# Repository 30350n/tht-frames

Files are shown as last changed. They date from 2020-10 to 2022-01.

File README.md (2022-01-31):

  

# THT-Frames

THT-Frames is a through hole version of [Mutable Instruments Frames](https://mutable-instruments.net/modules/frames/).
For the MCU a **128KB** STM32F103C8T6/STM32F103CBT6 "bluepill type" module is used.
**Warning! Most of the conventional boards floating around on ebay, aliexpress, etc. are 64KB. Those won't work with the provided firmware.**
I'd recommend picking one up from robotdyn ([website](https://robotdyn.com/)/[aliexpress](https://robotdyn.aliexpress.com/store/1950989)), these are the ones I use and they work without any problems.
You can also pickup a matching APM32 board if you want for a little cheaper. I've tested them and they also seem to work fine.

It also uses a different dac than the original, because it isn't available as a DIP package.

## Panels

Be sure to check out my [printable-instruments](https://github.com/30350n/printable-instruments) repository, which contains pcb panels for several Mutable Instuments modules including Frames.
That being said, any third-party panels should also fit with these boards.

## How to use

### Quickstart

To get started quickly, you can just download the gerbers for both pcbs and the compiled software `.hex` file from the [Releases](https://github.com/30350n/tht-frames/releases) section.

### Hardware

If you want to export the gerbers yourself or modify them, just clone the repository and open the hardware files with KiCad.

### Software

This project requires slightly modified software, because it uses two 2-channel DACs instead of the single 4-channel DAC the original uses.

If you want to build the software yourself, clone the [mutable-dev-environment](https://github.com/pichenettes/mutable-dev-environment) repository and follow the provided instructions to set it up.
After that, copy the patch from this repository (`software/tht-frames.patch`) to `mutable-dev-environment/eurorack-modules` and also `cd` to that directory.
Finally apply the patch via `git apply tht-frames.patch` and build the firmware as usual.

## Credits
- **[Mutable Instruments](https://github.com/pichenettes/eurorack)** provided the original hardware design files and software which this projects builds upon.
- **[SoundForce - Braids Through-hole](http://sound-force.nl/?page_id=3179)** gave me the idea for this project.

## License
- Hardware: cc-by-sa-3.0
- Software: MIT

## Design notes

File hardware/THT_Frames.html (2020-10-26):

# E:\projects\modular\modules\prototypes\THT_Frames\THT_Frames.sch

09/26/20 14:19:38

Eeschema (5.1.6)-1

Component Count:144

Ref | Qnty | Value | Part | Datasheet | Description | Vendor
C1, C2, C3, C4, C5 | 5 | 560pF | Device:C | ~ | Unpolarized capacitor
C6, C7, C8, C9, C16, C17 | 6 | 18pF | Device:C | ~ | Unpolarized capacitor
C10, C11, C12 | 3 | 10uF | Device:CP_Small | ~ | Polarized capacitor, small symbol
C13, C14 | 2 | 22uF | Device:CP | ~ | Polarized capacitor
C15, C18, C19, C20, C21, C22, C23, C26, C27, C34, C35, C36, C37, C38, C39 | 15 | 100nF | Device:C | ~ | Unpolarized capacitor
C24, C25, C28, C29 | 4 | 1uF | Device:CP | ~ | Polarized capacitor
D1, D2 | 2 | BAT85 | Diode:BAT85 | https://assets.nexperia.com/documents/data-sheet/BAT85.pdf | 30V 0.2A Schottky barrier single diode, DO-35
D3 | 1 | LED_CRGB | Device:LED_CRGB | ~ | RGB LED, cathode/red/green/blue
D4 | 1 | LED_FRAME | Device:LED | ~ | Light emitting diode
D5 | 1 | LED_CH4 | Device:LED | ~ | Light emitting diode
D6 | 1 | LED_CH3 | Device:LED | ~ | Light emitting diode
D7 | 1 | LED_CH2 | Device:LED | ~ | Light emitting diode
D8 | 1 | LED_CH1 | Device:LED | ~ | Light emitting diode
D9, D10, D11 | 3 | 1N5819 | Diode:1N5819 | http://www.vishay.com/docs/88525/1n5817.pdf | 40V 1A Schottky Barrier Rectifier Diode, DO-41
J1 | 1 | FRAME_IN | Connector:AudioJack2_SwitchT | ~ | Audio Jack, 2 Poles (Mono / TS), Switched T Pole (Normalling)
J2 | 1 | Serial | Connector_Generic:Conn_01x06 | ~ | Generic connector, single row, 01x06, script generated (kicad-library-utils/schlib/autogen/connector/)
J3, J18, J21 | 3 | Conn_01x12_Male | Connector:Conn_01x12_Male | ~ | Generic connector, single row, 01x12, script generated (kicad-library-utils/schlib/autogen/connector/)
J5 | 1 | STEP_OUT | Connector:AudioJack2_SwitchT | ~ | Audio Jack, 2 Poles (Mono / TS), Switched T Pole (Normalling)
J6 | 1 | 1_IN | Connector:AudioJack2_SwitchT | ~ | Audio Jack, 2 Poles (Mono / TS), Switched T Pole (Normalling)
J7 | 1 | 2_IN | Connector:AudioJack2_SwitchT | ~ | Audio Jack, 2 Poles (Mono / TS), Switched T Pole (Normalling)
J8 | 1 | 3_IN | Connector:AudioJack2_SwitchT | ~ | Audio Jack, 2 Poles (Mono / TS), Switched T Pole (Normalling)
J9 | 1 | 4_IN | Connector:AudioJack2_SwitchT | ~ | Audio Jack, 2 Poles (Mono / TS), Switched T Pole (Normalling)
J10 | 1 | 1_OUT | Connector:AudioJack2_SwitchT | ~ | Audio Jack, 2 Poles (Mono / TS), Switched T Pole (Normalling)
J11 | 1 | 2_OUT | Connector:AudioJack2_SwitchT | ~ | Audio Jack, 2 Poles (Mono / TS), Switched T Pole (Normalling)
J12 | 1 | 3_OUT | Connector:AudioJack2_SwitchT | ~ | Audio Jack, 2 Poles (Mono / TS), Switched T Pole (Normalling)
J13 | 1 | 4_OUT | Connector:AudioJack2_SwitchT | ~ | Audio Jack, 2 Poles (Mono / TS), Switched T Pole (Normalling)
J14 | 1 | POWER | Connector_Generic:Conn_02x08_Odd_Even | ~ | Generic connector, double row, 02x08, odd/even pin numbering scheme (row 1 odd numbers, row 2 even numbers), script generated (kicad-library-utils/schlib/autogen/connector/)
J15 | 1 | OFFSET_JUMPER | Connector_Generic:Conn_01x03 | ~ | Generic connector, single row, 01x03, script generated (kicad-library-utils/schlib/autogen/connector/)
J16 | 1 | ALL_IN | Connector:AudioJack2_SwitchT | ~ | Audio Jack, 2 Poles (Mono / TS), Switched T Pole (Normalling)
J17 | 1 | MIX_OUT | Connector:AudioJack2_SwitchT | ~ | Audio Jack, 2 Poles (Mono / TS), Switched T Pole (Normalling)
J19, J20, J22 | 3 | Conn_01x12_Female | Connector:Conn_01x12_Female | ~ | Generic connector, single row, 01x12, script generated (kicad-library-utils/schlib/autogen/connector/)
Q1 | 1 | 2N3904 | Transistor_BJT:2N3904 | https://www.fairchildsemi.com/datasheets/2N/2N3904.pdf | 0.2A Ic, 40V Vce, Small Signal NPN Transistor, TO-92
R1, R2, R3, R19, R20, R21, R22, R23, R24, R29, R30, R31, R32, R33, R34, R35, R36, R37, R38, R39, R40, R41, R42, R43, R44, R46, R47 | 27 | 100k | Device:R | ~ | Resistor
R4 | 1 | 240k | Device:R | ~ | Resistor
R5 | 1 | 33k | Device:R | ~ | Resistor
R6, R48, R49, R50, R51, R52 | 6 | 1k | Device:R | ~ | Resistor
R7 | 1 | 10k | Device:R | ~ | Resistor
R8, R9, R10, R11, R12, R13, R14, R15, R53, R54, R55, R56 | 12 | 100 | Device:R | ~ | Resistor
R16, R18 | 2 | 4.7k | Device:R | ~ | Resistor
R17 | 1 | 3.3k | Device:R | ~ | Resistor
R25, R26, R27, R28 | 4 | 510 | Device:R | ~ | Resistor
R45 | 1 | 49.9k | Device:R | ~ | Resistor
RV1, RV2, RV3, RV4, RV5, RV6 | 6 | 10k | Device:R_POT_MountingPin | ~ | Potentiometer with a mounting pin
SW1 | 1 | ADD | Switch:SW_SPST | ~ | Single Pole Single Throw (SPST) switch
SW2 | 1 | DEL | Switch:SW_SPST | ~ | Single Pole Single Throw (SPST) switch
SW3 | 1 | OFFSET | Switch:SW_SPDT | ~ | Switch, single pole double throw
U1, U5, U13 | 3 | TL072 | Amplifier_Operational:TL072 | http://www.ti.com/lit/ds/symlink/tl071.pdf | Dual Low-Noise JFET-Input Operational Amplifiers, DIP-8/SOIC-8
U2 | 1 | bluepill | custom:bluepill
U3 | 1 | LM1117-3.3 | Regulator_Linear:LM1117-3.3 | http://www.ti.com/lit/ds/symlink/lm1117.pdf | 800mA Low-Dropout Linear Regulator, 3.3V fixed output, TO-220/TO-252/TO-263/SOT-223
U4 | 1 | LM4040AIZ-10 | Reference_Voltage:LM4040DBZ-10 | http://www.ti.com/lit/ds/symlink/lm4040-n.pdf | 10.00V Precision Micropower Shunt Voltage Reference, SOT-23
U6, U7 | 2 | MCP4822 | Analog_DAC:MCP4822 | http://ww1.microchip.com/downloads/en/DeviceDoc/20002249B.pdf | 2-Channel 12-Bit D/A Converters with SPI Interface and Internal Reference (2.048V)
U8, U9 | 2 | TL074 | Amplifier_Operational:TL074 | http://www.ti.com/lit/ds/symlink/tl071.pdf | Quad Low-Noise JFET-Input Operational Amplifiers, DIP-14/SOIC-14
U12 | 1 | V2164 | custom:V2164

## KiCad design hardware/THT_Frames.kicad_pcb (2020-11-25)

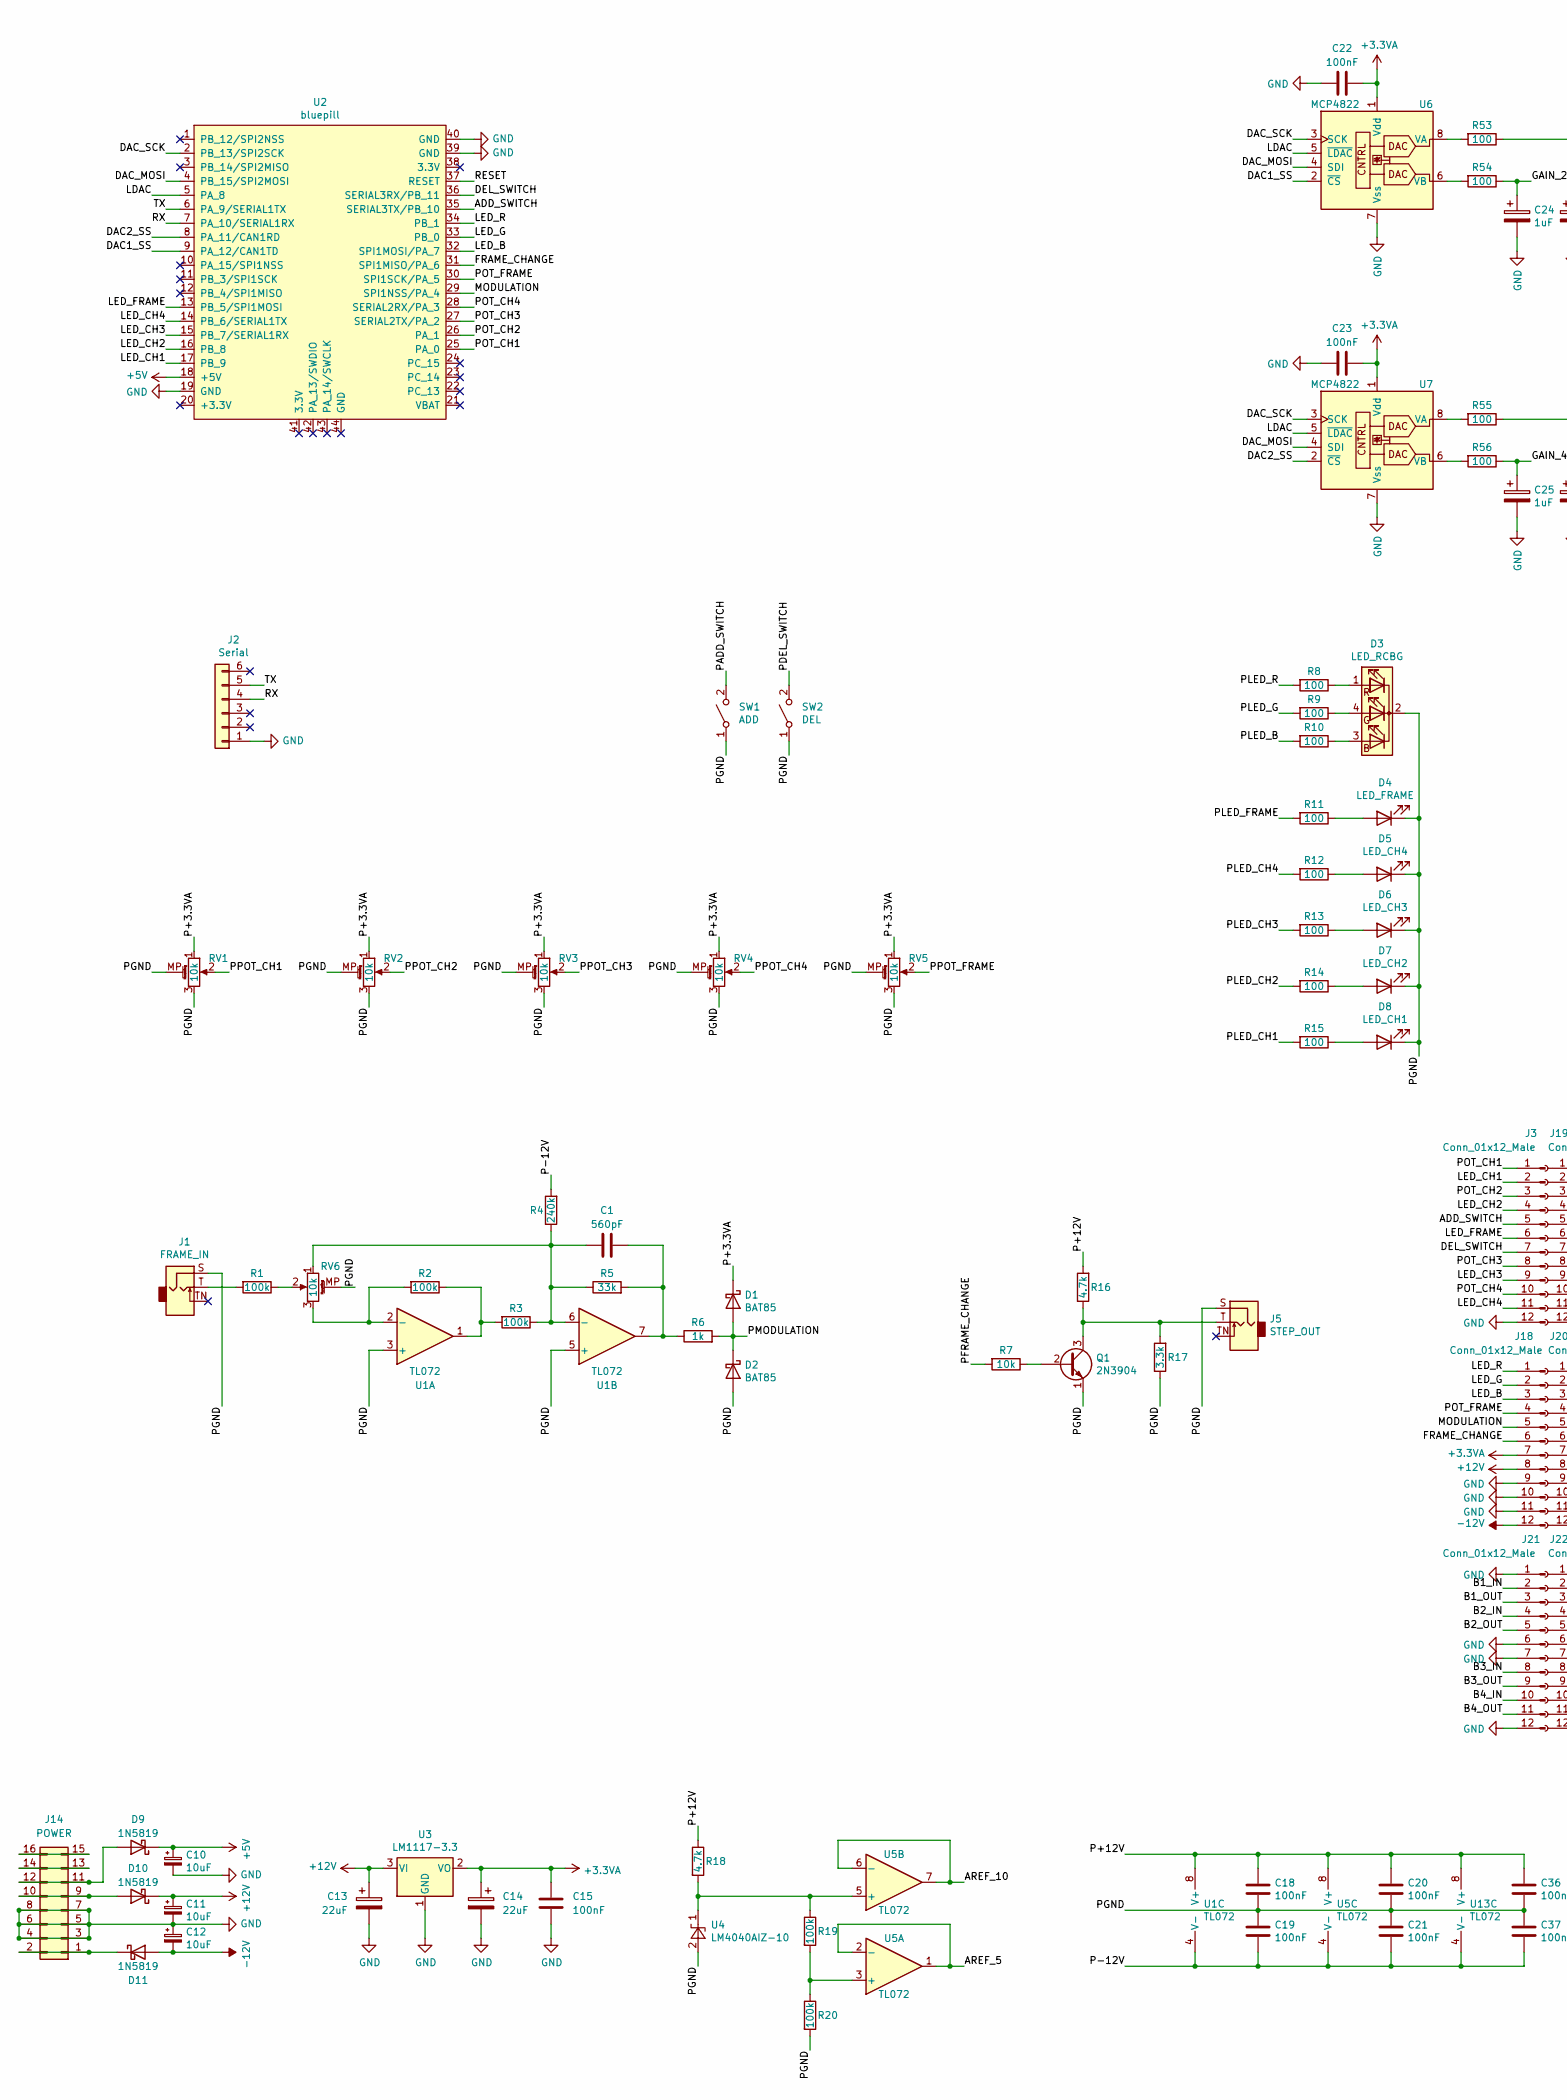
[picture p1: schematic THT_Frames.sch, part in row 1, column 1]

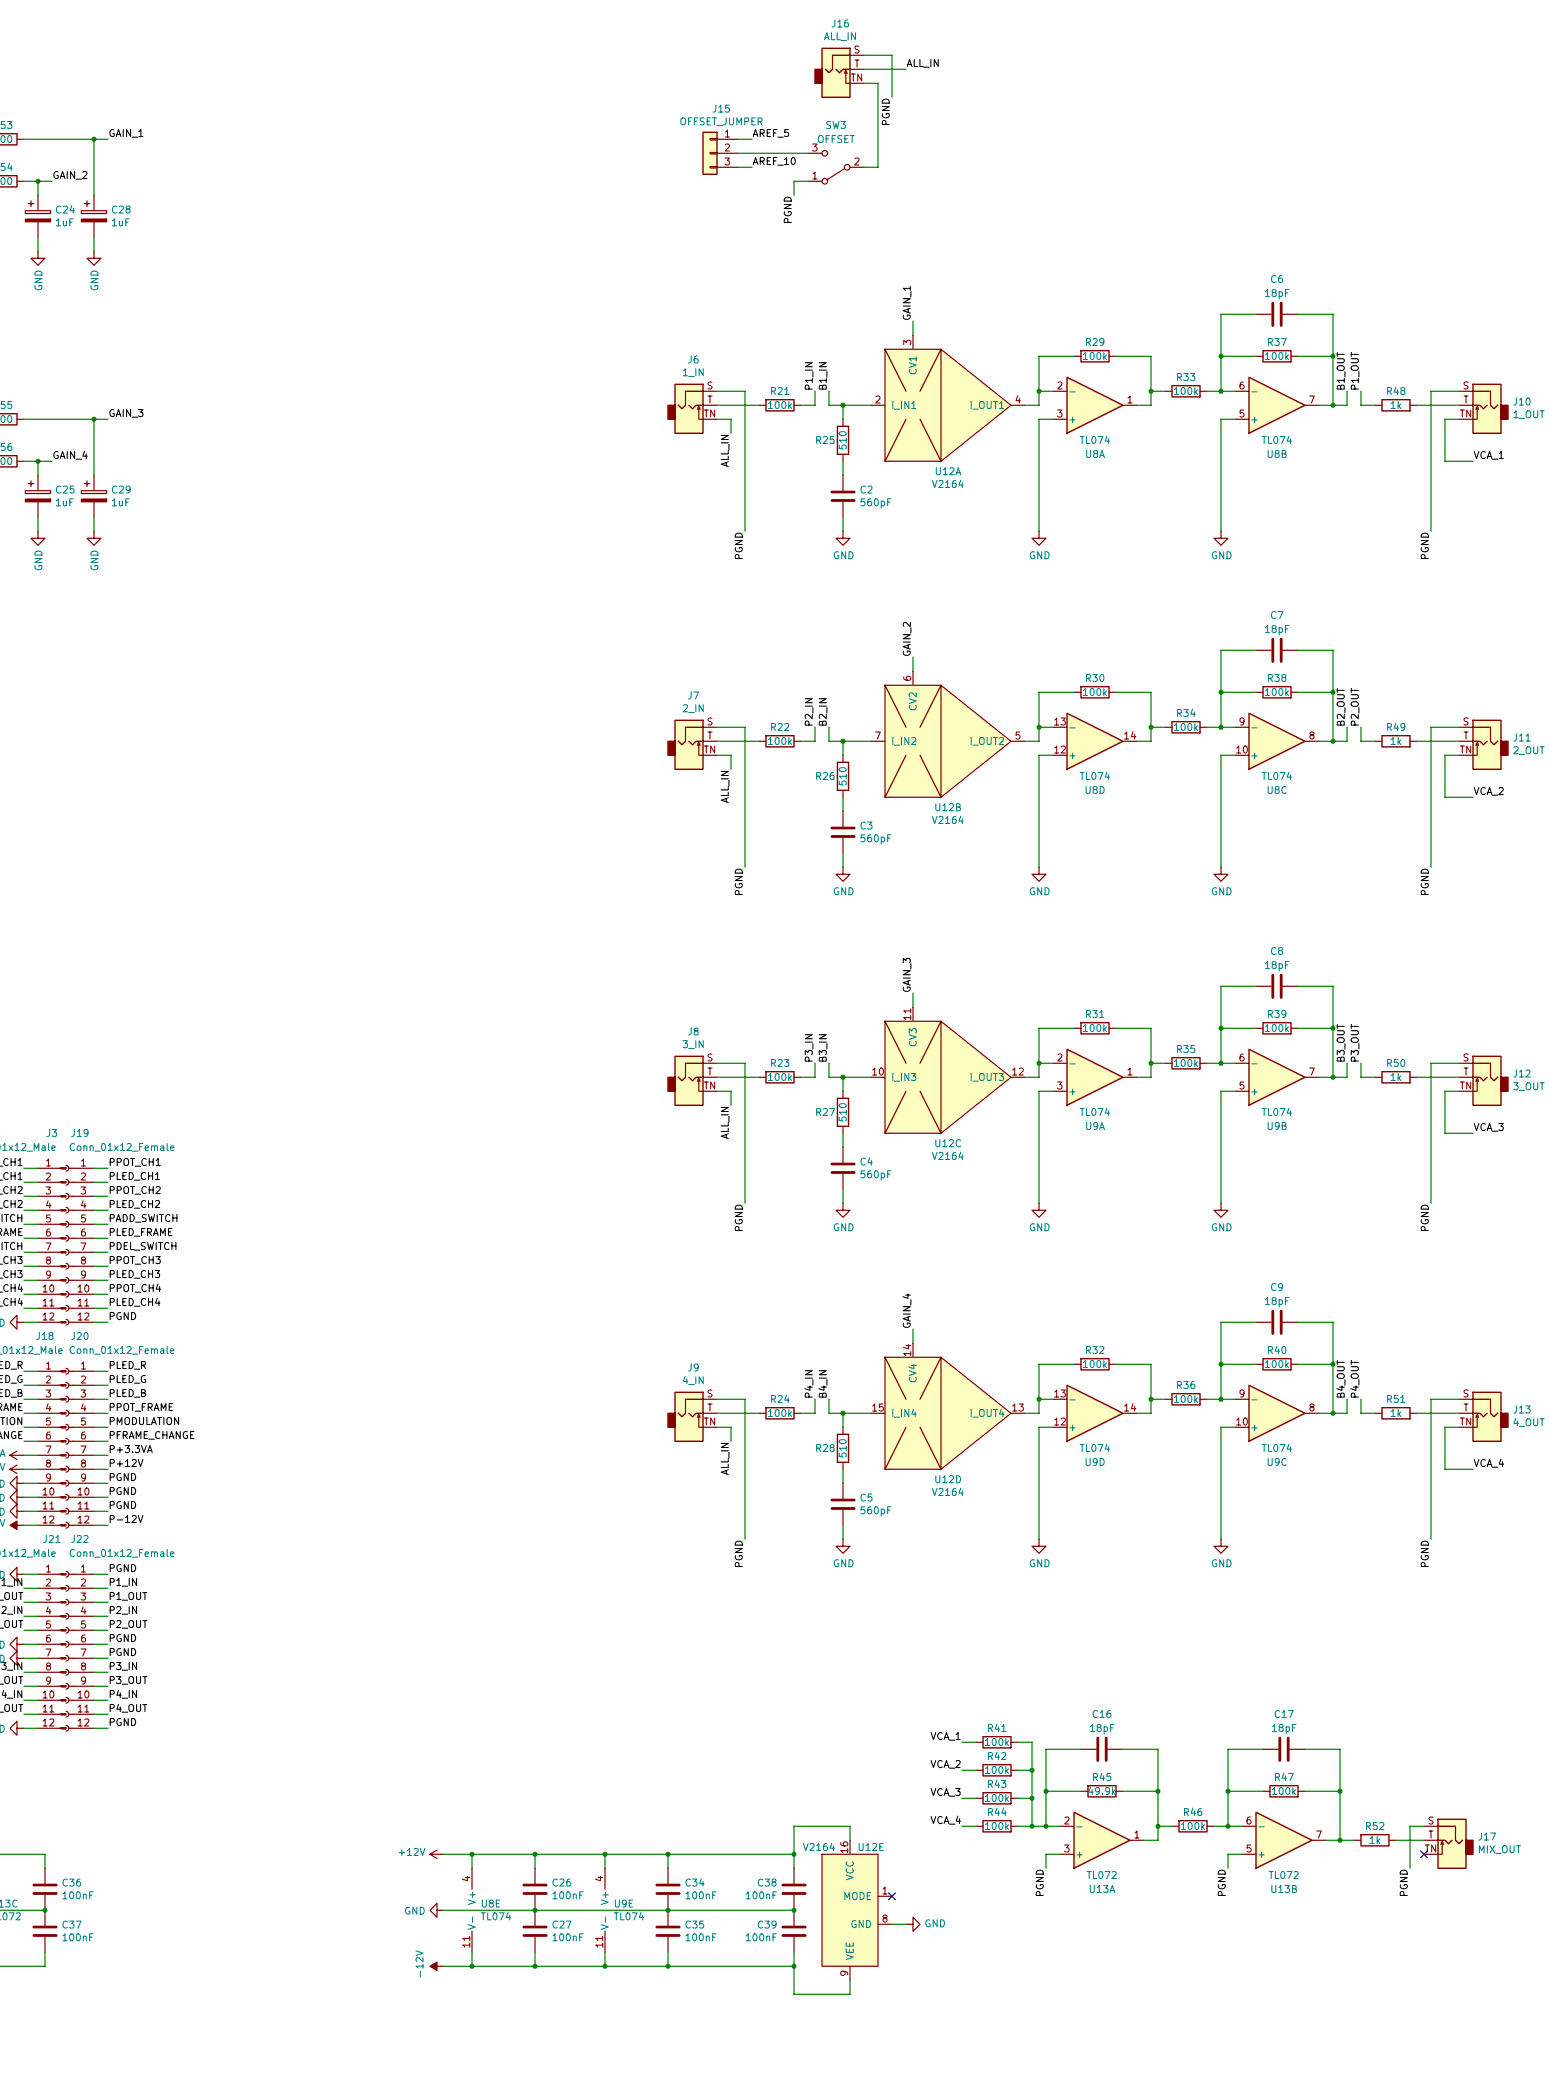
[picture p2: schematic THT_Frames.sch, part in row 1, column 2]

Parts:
C1, C2, C3, C4, C5: 560pF; C_Disc_D5.0mm_W2.5mm_P5.00mm_silk
C6, C7, C8, C9, C16, C17: 18pF; C_Disc_D5.0mm_W2.5mm_P5.00mm_silk
C10, C11, C12: 10uF; CP_Radial_D5.0mm_P2.00mm_silk
C13, C14: 22uF; CP_Radial_D5.0mm_P2.00mm_silk
C15, C18, C19, C20, C21, C22, C23, C26, C27, C34, C35, C36, C37, C38, C39: 100nF; C_Disc_D5.0mm_W2.5mm_P5.00mm_silk
C24, C25, C28, C29: 1uF; C_Disc_D7.5mm_W5.0mm_P5.00mm_silk
D1, D2: BAT85; D_DO-41_SOD81_P7.62mm_Horizontal_silk
D3: LED_RCBG; LED_D5.0mm-4_RGB
D4: LED_FRAME; LED_D5.0mm
D5: LED_CH4; LED_D3.0mm
D6: LED_CH3; LED_D3.0mm
D7: LED_CH2; LED_D3.0mm
D8: LED_CH1; LED_D3.0mm
D9, D10, D11: 1N5819; D_DO-41_SOD81_P10.16mm_Horizontal_silk
J1: FRAME_IN; Jack_3.5mm_QingPu_WQP-PJ398SM_Vertical_CircularHoles_better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
J2: Serial; PinHeader_1x06_P2.54mm_Vertical
J3, J18, J21: Conn_01x12_Male; PinHeader_1x12_P2.54mm_Vertical
J5: STEP_OUT; Jack_3.5mm_QingPu_WQP-PJ398SM_Vertical_CircularHoles_better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
J6: 1_IN; Jack_3.5mm_QingPu_WQP-PJ398SM_Vertical_CircularHoles_better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
J7: 2_IN; Jack_3.5mm_QingPu_WQP-PJ398SM_Vertical_CircularHoles_better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
J8: 3_IN; Jack_3.5mm_QingPu_WQP-PJ398SM_Vertical_CircularHoles_better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
J9: 4_IN; Jack_3.5mm_QingPu_WQP-PJ398SM_Vertical_CircularHoles_better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
J10: 1_OUT; Jack_3.5mm_QingPu_WQP-PJ398SM_Vertical_CircularHoles_better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
J11: 2_OUT; Jack_3.5mm_QingPu_WQP-PJ398SM_Vertical_CircularHoles_better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
J12: 3_OUT; Jack_3.5mm_QingPu_WQP-PJ398SM_Vertical_CircularHoles_better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
J13: 4_OUT; Jack_3.5mm_QingPu_WQP-PJ398SM_Vertical_CircularHoles_better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
J14: POWER; IDC-Header_2x08_P2.54mm_Vertical_eurorack
J15: OFFSET_JUMPER; PinHeader_1x03_P2.54mm_Vertical
J16: ALL_IN; Jack_3.5mm_QingPu_WQP-PJ398SM_Vertical_CircularHoles_better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
J17: MIX_OUT; Jack_3.5mm_QingPu_WQP-PJ398SM_Vertical_CircularHoles_better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
J19, J20, J22: Conn_01x12_Female; PinSocket_1x12_P2.54mm_Vertical
Q1: 2N3904; TO-92_Inline_Wide_silk
R1, R2, R3, R19, R20, R21, R22, R23, R24, R29, R30, R31, R32, R33, R34, R35, R36, R37, R38, R39, R40, R41, R42, R43, R44, R46, R47: 100k; R_Axial_DIN0207_L6.3mm_D2.5mm_P7.62mm_Horizontal_silk
R4: 240k; R_Axial_DIN0207_L6.3mm_D2.5mm_P7.62mm_Horizontal_silk
R5: 33k; R_Axial_DIN0207_L6.3mm_D2.5mm_P7.62mm_Horizontal_silk
R6, R48, R49, R50, R51, R52: 1k; R_Axial_DIN0207_L6.3mm_D2.5mm_P7.62mm_Horizontal_silk
R7: 10k; R_Axial_DIN0207_L6.3mm_D2.5mm_P7.62mm_Horizontal_silk
R8, R9, R10, R11, R12, R13, R14, R15, R53, R54, R55, R56: 100; R_Axial_DIN0207_L6.3mm_D2.5mm_P7.62mm_Horizontal_silk
R16, R18: 4.7k; R_Axial_DIN0207_L6.3mm_D2.5mm_P7.62mm_Horizontal_silk
R17: 3.3k; R_Axial_DIN0207_L6.3mm_D2.5mm_P7.62mm_Horizontal_silk
R25, R26, R27, R28: 510; R_Axial_DIN0207_L6.3mm_D2.5mm_P7.62mm_Horizontal_silk
R45: 49.9k; R_Axial_DIN0207_L6.3mm_D2.5mm_P7.62mm_Horizontal_silk
RV1, RV2, RV3, RV4, RV5, RV6: 10k; Potentiometer_Alps_RK09K_Single_Vertical_better_origin
SW1: ADD; Push_E-Switch_KS01Q01_silk_better_origin
SW2: DEL; Push_E-Switch_KS01Q01_silk_better_origin
SW3: OFFSET; sw_spdt_slide_CS12ANW03
U1, U5, U13: TL072; DIP-8_W7.62mm_Socket_LongPads_silk
U2: bluepill
U3: LM1117-3.3; TO-220-3_Horizontal_TabDown_silk
U4: LM4040AIZ-10; TO-92_Inline_Wide_silk
U6, U7: MCP4822; DIP-8_W7.62mm_Socket_LongPads_silk
U8, U9: TL074; DIP-14_W7.62mm_Socket_LongPads_silk
U12: V2164; DIP-16_W7.62mm_Socket_LongPads_silk

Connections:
+3.3VA: C14.1, C15.1, C22.1, C23.1, J18.7, U3.2 (VO), U6.1 (Vdd), U7.1 (Vdd)
+5V: C10.1, D9.1 (K), U2.18 (+5V)
+12V: C11.1, C13.1, C26.1, C34.1, C38.1, D10.1 (K), J18.8, U3.3 (VI), U8.4 (V+), U9.4 (V+), U12.16 (VCC)
-12V: C12.2, C27.2, C35.2, C39.2, D11.2 (A), J18.12, U8.11 (V-), U9.11 (V-), U12.9 (VEE)
/ADD_SWITCH: J3.5, U2.35 (SERIAL3TX/PB_10)
/ALL_IN: J6.TN, J7.TN, J8.TN, J9.TN, J16.T
/AREF_5: J15.1, U5.1, U5.2 (-)
/AREF_10: J15.3, U5.6 (-), U5.7
/B1_IN: J21.2, R25.1, U12.2 (I_IN1)
/B1_OUT: C6.1, J21.3, R37.2, U8.7
/B2_IN: J21.4, R26.1, U12.7 (I_IN2)
/B2_OUT: C7.1, J21.5, R38.2, U8.8
/B3_IN: J21.8, R27.1, U12.10 (I_IN3)
/B3_OUT: C8.1, J21.9, R39.2, U9.7
/B4_IN: J21.10, R28.1, U12.15 (I_IN4)
/B4_OUT: C9.1, J21.11, R40.2, U9.8
/DAC1_SS: U2.9 (PA_12/CAN1TD), U6.2 (~CS)
/DAC2_SS: U2.8 (PA_11/CAN1RD), U7.2 (~CS)
/DAC_MOSI: U2.4 (PB_15/SPI2MOSI), U6.4 (SDI), U7.4 (SDI)
/DAC_SCK: U2.2 (PB_13/SPI2SCK), U6.3 (SCK), U7.3 (SCK)
/DEL_SWITCH: J3.7, U2.36 (SERIAL3RX/PB_11)
/FRAME_CHANGE: J18.6, U2.31 (SPI1MISO/PA_6)
/GAIN_1: C28.1, R53.1, U12.3 (CV1)
/GAIN_2: C24.1, R54.1, U12.6 (CV2)
/GAIN_3: C29.1, R55.1, U12.11 (CV3)
/GAIN_4: C25.1, R56.1, U12.14 (CV4)
/LDAC: U2.5 (PA_8), U6.5 (~LDAC), U7.5 (~LDAC)
/LED_B: J18.3, U2.32 (SPI1MOSI/PA_7)
/LED_CH1: J3.2, U2.17 (PB_9)
/LED_CH2: J3.4, U2.16 (PB_8)
/LED_CH3: J3.9, U2.15 (PB_7/SERIAL1RX)
/LED_CH4: J3.11, U2.14 (PB_6/SERIAL1TX)
/LED_FRAME: J3.6, U2.13 (PB_5/SPI1MOSI)
/LED_G: J18.2, U2.33 (PB_0)
/LED_R: J18.1, U2.34 (PB_1)
/MODULATION: J18.5, U2.29 (SPI1NSS/PA_4)
/P1_IN: J22.2, R21.1
/P1_OUT: J22.3, R48.1
/P2_IN: J22.4, R22.1
/P2_OUT: J22.5, R49.1
/P3_IN: J22.8, R23.1
/P3_OUT: J22.9, R50.1
/P4_IN: J22.10, R24.1
/P4_OUT: J22.11, R51.1
/P+3.3VA: D1.1 (K), J20.7, RV1.1, RV2.1, RV3.1, RV4.1, RV5.1
/P+12V: C18.1, C20.1, C36.1, J20.8, R16.2, R18.1, U1.8 (V+), U5.8 (V+), U13.8 (V+)
/P-12V: C19.2, C21.2, C37.2, J20.12, R4.2, U1.4 (V-), U5.4 (V-), U13.4 (V-)
/PADD_SWITCH: J19.5, SW1.2 (B)
/PDEL_SWITCH: J19.7, SW2.2 (B)
/PFRAME_CHANGE: J20.6, R7.2
/PGND: C18.2, C19.1, C20.2, C21.1, C36.2, C37.1, D2.2 (A), D3.2 (K), D4.1 (K), D5.1 (K), D6.1 (K), D7.1 (K), D8.1 (K), J1.S, J5.S, J6.S, J7.S, J8.S, J9.S, J10.S, J11.S, J12.S, J13.S, J16.S, J17.S, J19.12, J20.9, J20.10, J20.11, J22.1, J22.6, J22.7, J22.12, Q1.1 (E), R17.1, R20.2, RV1.3, RV1.MP (MountPin), RV2.3, RV2.MP (MountPin), RV3.3, RV3.MP (MountPin), RV4.3, RV4.MP (MountPin), RV5.3, RV5.MP (MountPin), RV6.MP (MountPin), SW1.1 (A), SW2.1 (A), SW3.1 (A), U1.3 (+), U1.5 (+), U4.2 (A), U13.3 (+), U13.5 (+)
/PLED_B: J20.3, R10.2
/PLED_CH1: J19.2, R15.2
/PLED_CH2: J19.4, R14.2
/PLED_CH3: J19.9, R13.2
/PLED_CH4: J19.11, R12.2
/PLED_FRAME: J19.6, R11.2
/PLED_G: J20.2, R9.2
/PLED_R: J20.1, R8.2
/PMODULATION: D1.2 (A), D2.1 (K), J20.5, R6.2
/POT_CH1: J3.1, U2.25 (PA_0)
/POT_CH2: J3.3, U2.26 (PA_1)
/POT_CH3: J3.8, U2.27 (SERIAL2TX/PA_2)
/POT_CH4: J3.10, U2.28 (SERIAL2RX/PA_3)
/POT_FRAME: J18.4, U2.30 (SPI1SCK/PA_5)
/PPOT_CH1: J19.1, RV1.2
/PPOT_CH2: J19.3, RV2.2
/PPOT_CH3: J19.8, RV3.2
/PPOT_CH4: J19.10, RV4.2
/PPOT_FRAME: J20.4, RV5.2
/RESET: U2.37 (RESET)
/RX: J2.4, U2.7 (PA_10/SERIAL1RX)
/TX: J2.5, U2.6 (PA_9/SERIAL1TX)
/VCA_1: J10.TN, R41.1
/VCA_2: J11.TN, R42.1
/VCA_3: J12.TN, R43.1
/VCA_4: J13.TN, R44.1
GND: C2.2, C3.2, C4.2, C5.2, C10.2, C11.2, C12.1, C13.2, C14.2, C15.2, C22.2, C23.2, C24.2, C25.2, C26.2, C27.1, C28.2, C29.2, C34.2, C35.1, C38.2, C39.1, J2.1, J3.12, J14.3, J14.4, J14.5, J14.6, J14.7, J14.8, J18.9, J18.10, J18.11, J21.1, J21.6, J21.7, J21.12, U2.19 (GND), U2.39 (GND), U2.40 (GND), U3.1 (GND), U6.7 (Vss), U7.7 (Vss), U8.3 (+), U8.5 (+), U8.10 (+), U8.12 (+), U9.3 (+), U9.5 (+), U9.10 (+), U9.12 (+), U12.8 (GND)
unnamed: C1.1, R5.2, R6.1, U1.7
unnamed: C1.2, R3.1, R4.1, R5.1, RV6.1, U1.6 (-)
unnamed: C2.1, R25.2
unnamed: C3.1, R26.2
unnamed: C4.1, R27.2
unnamed: C5.1, R28.2
unnamed: C6.2, R33.2, R37.1, U8.6 (-)
unnamed: C7.2, R34.2, R38.1, U8.9 (-)
unnamed: C8.2, R35.2, R39.1, U9.6 (-)
unnamed: C9.2, R36.2, R40.1, U9.9 (-)
unnamed: C16.1, R45.1, R46.2, U13.1
unnamed: C16.2, R41.2, R42.2, R43.2, R44.2, R45.2, U13.2 (-)
unnamed: C17.1, R47.2, R52.2, U13.7
unnamed: C17.2, R46.1, R47.1, U13.6 (-)
unnamed: D3.1 (RA), R8.1
unnamed: D3.3 (BA), R10.1
unnamed: D3.4 (GA), R9.1
unnamed: D4.2 (A), R11.1
unnamed: D5.2 (A), R12.1
unnamed: D6.2 (A), R13.1
unnamed: D7.2 (A), R14.1
unnamed: D8.2 (A), R15.1
unnamed: D9.2 (A), J14.11, J14.12
unnamed: D10.2 (A), J14.9, J14.10
unnamed: D11.1 (K), J14.1, J14.2
unnamed: J1.T, R1.2
unnamed: J5.T, Q1.3 (C), R16.1, R17.2
unnamed: J6.T, R21.2
unnamed: J7.T, R22.2
unnamed: J8.T, R23.2
unnamed: J9.T, R24.2
unnamed: J10.T, R48.2
unnamed: J11.T, R49.2
unnamed: J12.T, R50.2
unnamed: J13.T, R51.2
unnamed: J14.13, J14.14
unnamed: J14.15, J14.16
unnamed: J15.2, SW3.3 (C)
unnamed: J16.TN, SW3.2 (B)
unnamed: J17.T, R52.1
unnamed: Q1.2 (B), R7.1
unnamed: R1.1, RV6.2
unnamed: R2.1, R3.2, U1.1
unnamed: R2.2, RV6.3, U1.2 (-)
unnamed: R18.2, R19.1, U4.1 (K), U5.5 (+)
unnamed: R19.2, R20.1, U5.3 (+)
unnamed: R29.1, R33.1, U8.1
unnamed: R29.2, U8.2 (-), U12.4 (I_OUT1)
unnamed: R30.1, R34.1, U8.14
unnamed: R30.2, U8.13 (-), U12.5 (I_OUT2)
unnamed: R31.1, R35.1, U9.1
unnamed: R31.2, U9.2 (-), U12.12 (I_OUT3)
unnamed: R32.1, R36.1, U9.14
unnamed: R32.2, U9.13 (-), U12.13 (I_OUT4)
unnamed: R53.2, U6.8 (VA)
unnamed: R54.2, U6.6 (VB)
unnamed: R55.2, U7.8 (VA)
unnamed: R56.2, U7.6 (VB)

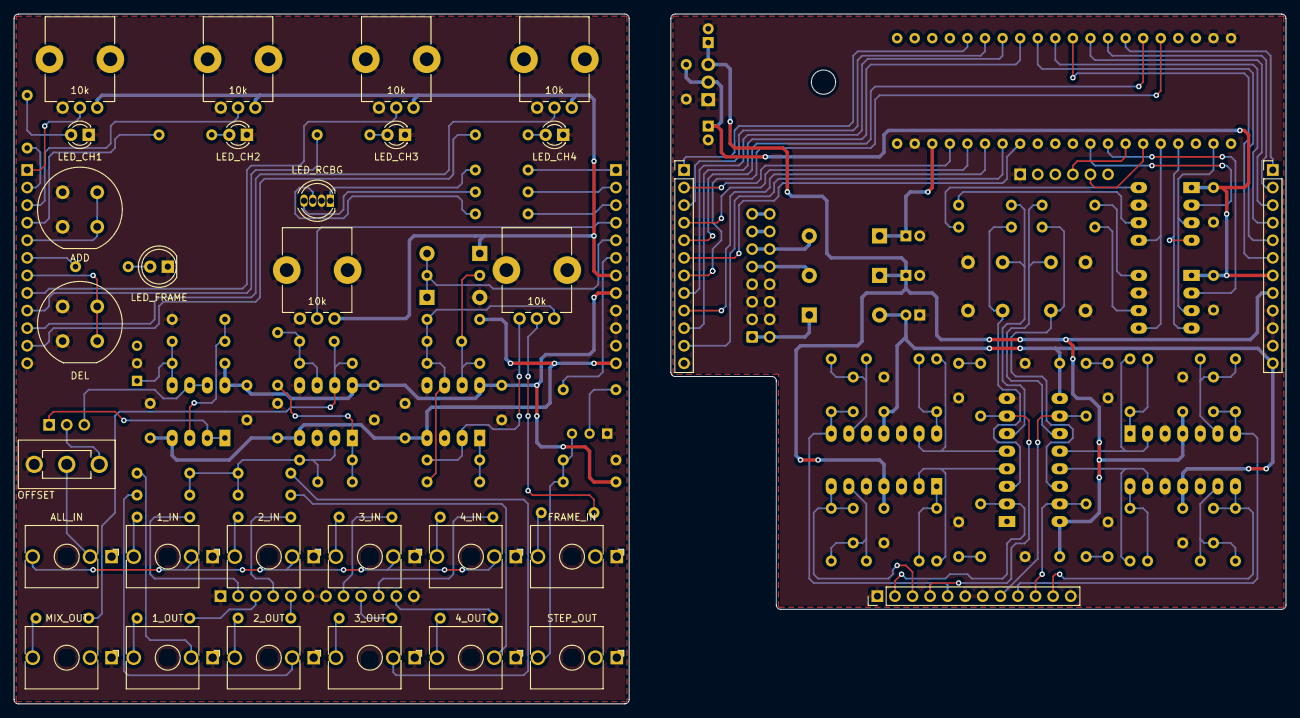
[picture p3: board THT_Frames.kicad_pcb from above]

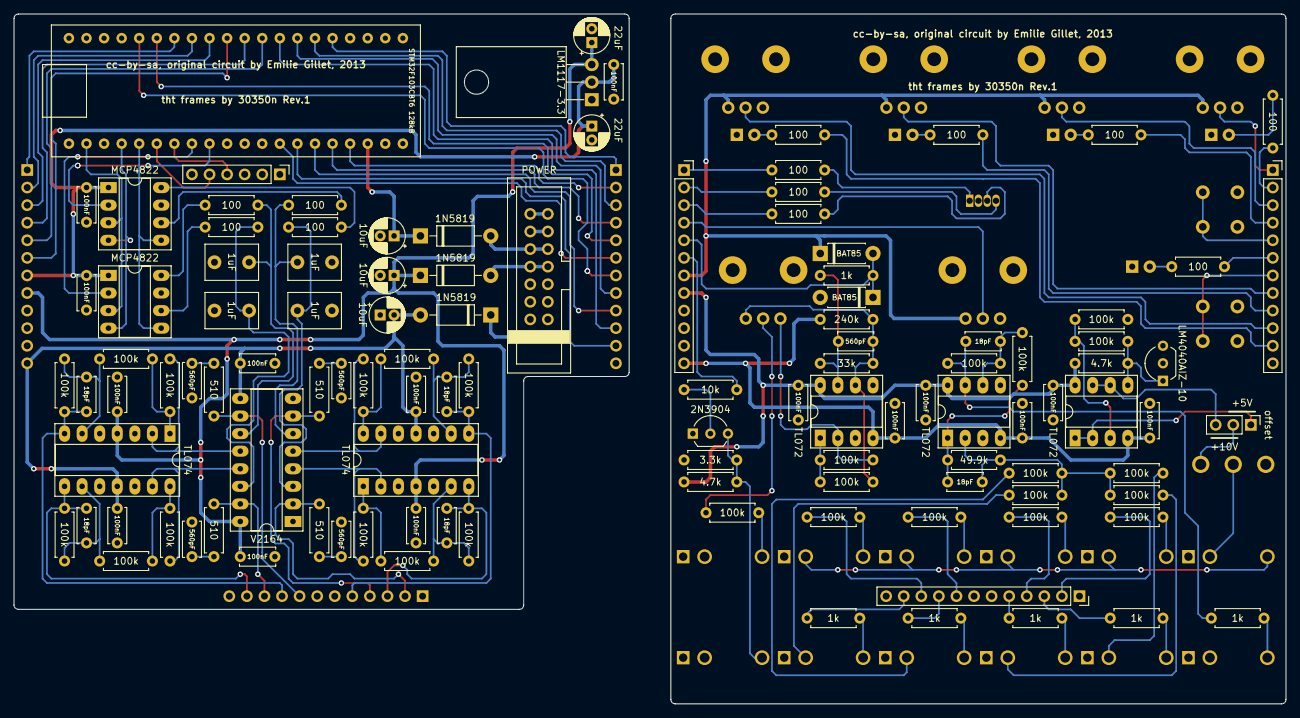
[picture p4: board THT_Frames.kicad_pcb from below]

Board: 2 copper layers, 183.8 x 99.7 mm, 144 parts (114 on the bottom side), 135 nets.

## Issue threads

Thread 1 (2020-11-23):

A Couple of (Stupid) Questions

angiamusic, 2020-11-23:
Hello!

First of all, thank you so much for this project! It's always lovely to see more and more Mutable designs being adapted to THT, especially for amateurs in SDIY like myself.

I had a couple of questions if you didn't mind:

1. Is this project actually complete and ready to get PCBs made, or is it still WIP?
I ask because I haven't been able to come across this elsewhere and only stumbled upon it through the "eurorack" topic on Git.

2. Will the Printable Instruments Frames panel work with this, along with any other Frames panel, or does this require it's own panel design?

3. Is there an official BOM? I was able to gather one from the kicad files, but I would like to know if you have an official one in case there are amendments that I missed.

Thank you for your work, and I look forward to this as my next project!

Aditya

30350n, 2020-11-25:
Hey!

Sure I'll try to answer them as good as I can:

1. This project is basically complete, I already ordered a first batch and assembled it. There were some minor issues which I fixed (see https://github.com/30350n/tht-frames/commit/59306a8ae20bcc9e90746306323c4285c5344e31, https://github.com/30350n/tht-frames/commit/50d177925b66d5548b39c43762f530c301673435, https://github.com/30350n/tht-frames/commit/25838d59e854389ca7136ca0f5d0b7b73fe9cf8d).

2. This should fit any standard Frames panel, including the printable-instruments ones of course. (I'm using those myself and ordered them in the same batch).

3. I haven't found time to put together a proper bom, you should be able to generate one in KiCad though. Parts should be fairly standard/have standard packages, the most important thing is that you get a STM32F103CBT6 with **128kB** of RAM.

If you actually build this, make sure to share your experiences! And if you run into any issues along the way, just ask me here or via discord (Bobbe#8552).

Thanks a lot for checking out the project!

30350n, 2020-11-25:
Two more things I forgot:
- This requires slightly modified firmware, because it's using a different dac. I also haven't had the time to upload that here, but I'll probably do that in the next week or so.
- Contrary to an original Frames, this variant requires a 5V power rail.

angiamusic, 2020-11-25:
Thank you for your reply! I am getting PCBs manufactured currently, after having built the THT Braids I'm really looking forward to starting this build. :)

Hope to see the modified firmware soon too.

30350n, 2020-11-25:
Just added a software patch, aswell as some more information to the README and a release containing a pre-compiled `.hex` file. ^^

pierstu, 2020-12-29:
Hello, i'm about to send the pcbs to fab too! Thanks for this project.
I'm having an error when trying to compile Parasite for Frames tht

- patched the .patch file to eurorack-modules (which applied to frames/drivers/dac.cc and dac.h)
- copied these files to frames-parasite/drivers
- bootoader compiled successfully
- tried to compile the Parasite firmware `make -f frames-parasite hex`

> `build/frames-parasite/startup_stm32f10x_md.o: In function `LoopFillZerobss':
(.text.Reset_Handler+0x2e): undefined reference to `main'
collect2: error: ld returned 1 exit status
make: *** [build/frames-parasite/frames-parasite.elf] Error 1
vagrant@vagrant-ubuntu-trusty-64:/vagrant/eurorack-modules$ `

Win 10 last week update, vbox 6.1.16, vagrant 2.2.14
Anyone could guess better than me whats going on?

Thanks for this great project @30350n, hope we'll have more and more of these Mutable tht ports

30350n, 2020-12-29:
Hey! Thanks for checking out the project. I actually didn't knew a parasites firmware for frames existed, but I just tried to replicated your issue and well ... this has been quite a bumpy road... ^^

Two questions:
- How did you add the parasites firmware exactly?
- Where does the `frames-parasite` makefile come from?

Regardless, this is what I just did to get it working:
1. setup the `mutable-dev-environment` normally, with the default `eurorack` repository
2. add the `parasites` repository as a remote and checkout it's `master` branch (this might require you to create a second, local "parasites-master" branch)
3. go into the `stmlib` folder/submodule and checkout the `master` branch of the original repository (this was necessary for me, because it otherwise tried to call the compiler from `/usr/local/gcc-arm-none-eabi-5_4-2016q3/bin/arm-none-eabi-g++` instead of `/usr/local/arm/bin/arm-none-eabi-g++` (this could probably also be fixed by properly installing that version of the toolchain, but I didn't bother))
4. apply the `tht-frames.patch` from this repository and build the code via `make -f frames/makefile hex`

Note: I actually use `make -f frames/makefile upload`, without a connected programmer (because that generates the `frames_bootloader_combo.hex`) and then flash it manually via the STM32CubeProgrammer utility on Windows.

30350n, 2020-12-29:
Here's the [hex file](https://github.com/30350n/tht-frames/files/5752457/frames_bootloader_combo_hex.zip) btw, if you don't want to mess with building it yourself. ^^

pierstu, 2020-12-29:
Thank you! I downloaded the Parasite zip from github, renamed the frames folder to frames-parasite and pasted it into the eurorack folder. I often rename the target dirs in the makefiles to get a corresponding output in the build folder, so it's more clear.
Thanks for the build anyway !

30350n, 2020-12-29:
Ah okay, maybe the renaming somehow messed up the linking process. ¯\_(ツ)_/¯

ijnekenamay, 2022-04-21:
Hello!
It appears that the specified microcontroller (robotdyn) is currently out of stock.
It seems that 128kb blue pill is a kind of mutant and hard to find in the market.
Is there any store where I can easily get it now?

30350n, 2022-04-21:
Yeah, 128kb blue pills have pretty much become complete unobtainium in the last year and a half or so.
Normal 64k ones are still available and i've heard of people being lucky and getting 128k variants when buying 64k variants, but it's a gamble.
I'm not really sure where I'd get one at this point in time either, sorry :/

Genmaizen, 2023-06-10:
Hi Bobbe,
I´m TL1A from Kristian´s Discord server. I built your THT-Frames yesterday. The PCBs look very nice and it was easy to solder all the parts (sources most of them from TME.eu). I used an AS2164 (electric druid) instead of the V2164.

Unfortunately, the Frame animation acts erratic. I try to explain it in the following using the walkthrough example from Emilie:
-	Frame 1: After first power-up (or reset) the FRAME knob is white and the keyframe indication LED is off. Pressed the ADD button. Set the first attenuator knob to maximum level, and second to its minimum level. The FRAME knob is illuminated in red and that the keyframe indicator is also lit.
-	Frame 2: Rotated the FRAME knob to its medium position (12 o'clock). Pressed the ADD button. Set the first knob to its minimum level, and second to its maximum level. This second keyframe looks orange.
-	Frame 3: Rotated the FRAME knob to its final position (5 o'clock). Pressed the ADD button to create the last keyframe in the animation. Set 1st and 2nd knob to medium levels. This third keyframe is given a yellow colour.

The above three steps behave normally. But now when moving the Frames knob back and forth there is no animation like programmed. The LEDs 1 and 2 lights somehow get dimmer, but do not go out when they should and eventually light up fully and stay like that. The VCO sound (saw and square) moves in loudness like indicated by the LED 1 and 2 indicators. The keyframe indicators and the FRAME knobs behave like that:
-	Frame 1: The keyframe indicator lights steady and the FRAME knob flickers
-	Frame 2: The keyframe indicator as well as the FRAME knob flickers
-	Frame 3: Both indicator lights are steadily on.

It get´s even stranger when I move the Attenuator knobs. Then the LED 1 and 2 also begin to flicker and the saw and square wave sound changes to a high pitched noise. This behaviour changes a bit when moving several times through the Frames. Also, when powering up without reset or after the second powerup the flickering already starts after setting the first Frame. To sum up, in principle the Frame animation acts erratic.
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
Genmaizen, 2023-06-10:
Well, it really feels that the STM32F103C8T6 is a problem. Although they are 128kb. Do you think that I really need the STM32F103C8T6 (as you mentioned above) and STM32F103C8T6 simply do not work? This is odd, because Beaks and Braids work well with the STM32F103C8T6.

Genmaizen, 2023-06-10:
Or do I need calibration? I did not find any info on that, except for holding the DEL button when powering up. But I think even that is just meant for the parasites Firmware.

Genmaizen, 2023-06-12:
I used an LM4040BIZ-10NOPB for the 10 V reference. At the offset pins I measure 5.742 and 11.228 Volts. At the LM4040BIZ itself I measure 11.542 Volts. Is that a clue?

30350n, 2023-06-12:
The flickering sounds like a power issue or issue with the mcu, as these are directly driven by it (via PWM probably).
> I also noticed that different STM32 act differently - more or less flickering, distortion or eratic behaviour.
This also makes me think it's just a defective/out of spec bluepill module, I'd probably try replacing that.

> I used an LM4040BIZ-10NOPB for the 10 V reference. At the offset pins I measure 5.742 and 11.228 Volts. At the LM4040BIZ itself I measure 11.542 Volts. Is that a clue?
That's definitely not right and either sounds like your LM4040 is defective, not soldered properly or just really out of spec. The B variant should have a +-0.2% tolerance, so pin 1 should be off by 20mV at most. Where did you get it from?

Genmaizen, 2023-06-12:
Thanks very much for your comments!

I bought the LM4040 at tme.eu. I tried to somhow measure another one out of this batch, but it is not easy to build up the test circuit for that because one needs a load on the LM4040... I also was a bit confused concerning the pin description in the schematic. 1 is cathode and 2 is anode. 1 and 2 should mean Pin 1 and Pin 2 of the LM4040? However in the LM4040BIZ-10NOPB documentation Pin 1 is anode and Pin 2 is cathode. Is this something?

30350n, 2023-06-12:
Hah! Yeah okay, the LM4040 is on me, seems like I swapped the pins and never even noticed ...
Welllll, I should probably fix that at some point 😅 .

Genmaizen, 2023-06-12:
Wohoooo, I contributed 😉

Anyhow, do I understand it correctly that this is just a schematic designation issue and not a PCB problem. So I don´t have to cross the legs of the LM4040 on the PCB? That means, the silkscreen shows the correct orientation of the LM4040.

30350n, 2023-06-12:
No, it is a PCB problem, but it shouldn't matter *much*. If you want the offset to work correctly, you should solder it like this.
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

Genmaizen, 2023-06-12:
Cool, thanks! Solved an issue 👍

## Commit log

2020-10-26 Add development hardware files
    [THT_Frames.kicad_pcb, THT_Frames.sch]
2020-10-26 Fix swapped leds on channels 3/4
    [THT_Frames.kicad_pcb, THT_Frames.sch]
2020-10-26 Use easy to solder to-92 footprint, bigger footprints for 1uF caps
    [THT_Frames.kicad_pcb, THT_Frames.sch]
2020-10-26 Add silkscreen markings to offset jumper
    [THT_Frames.kicad_pcb]
2020-10-26 Fix accidentally inverted internal offset voltages
    [THT_Frames.kicad_pcb, THT_Frames.sch]
2020-11-25 Bump revision number on main pcb
    [THT_Frames.kicad_pcb]
2022-01-31 Add schematic cache

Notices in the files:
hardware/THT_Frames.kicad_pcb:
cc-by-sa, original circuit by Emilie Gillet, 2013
